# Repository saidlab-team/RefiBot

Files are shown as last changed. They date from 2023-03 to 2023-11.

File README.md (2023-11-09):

# RefiBot

<div align="center">
    <h1>🤖🛠️ RefiBot 🛠️🤖</h1>
</div>

<p align="center">
<a href="https://github.com/saidlab-team/RefiBot/blob/main/LICENSE" target="_blank">
    
</a>


<a href="https://twitter.com/socialdroneslab" target="_blank">
    
</a>

> A small educational robot made from recycled plastic from fishnets

RefiBot is an open-source educational robot designed to be built at home using recycled plastics from fishnets, promoting sustainability and encouraging learning.
The project includes hardware designs, software libraries, and documentation to help you build and program your RefiBot.

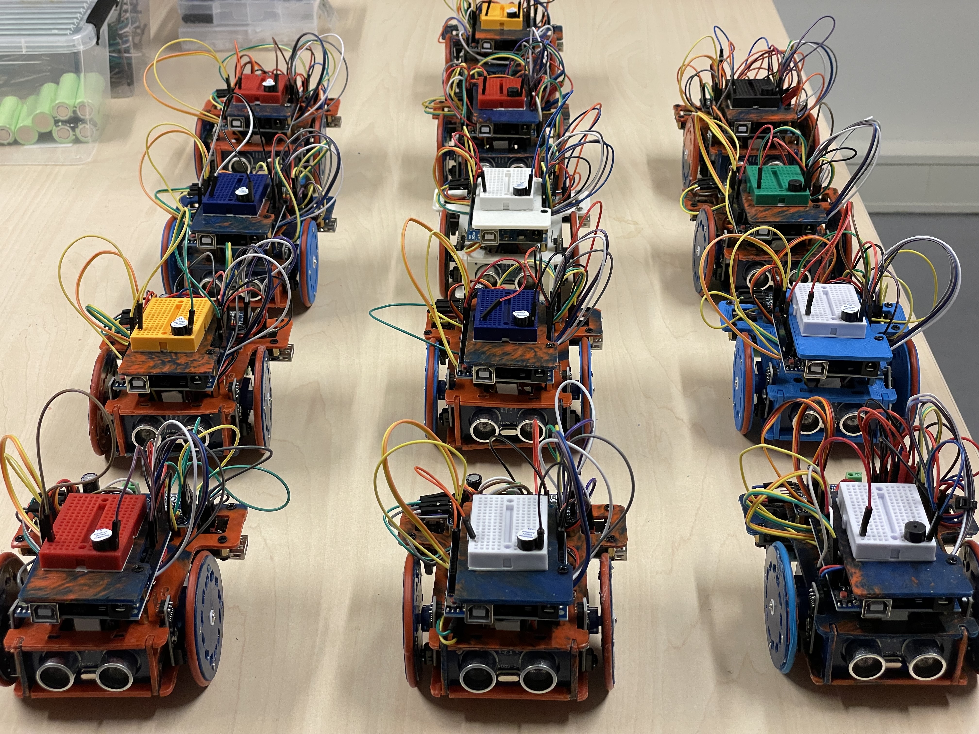
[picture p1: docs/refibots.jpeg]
RefiBot_Image


Citing
-------

Please cite the  following paper ([https://www.sciencedirect.com/science/article/pii/S2468067223000913](https://www.sciencedirect.com/science/article/pii/S2468067223000913)) when using ReFiBot for your research:

```bibtex
  @article{PANTOS2023Refibot,
    title = {The ReFiBot makers guide: Fostering academic open science and circularity with a robotic educational kit},
    journal = {HardwareX},
    volume = {16},
    pages = {e00484},
    year = {2023},
    issn = {2468-0672},
    doi = {https://doi.org/10.1016/j.ohx.2023.e00484},
    url = {https://www.sciencedirect.com/science/article/pii/S2468067223000913},
    author = {Christos Pantos and Jurrian Doornbos and Gonzalo Mier and João Valente},
    keywords = {Robotics, Education, Circularity, Open-science, Recycling, Low-cost}
  }
```

# Table of Contents

- [Features](#features)
  - [Key Features](#key-features)
  - [Possible Applications](#possible-applications)
- [Hardware](#hardware)
  - [Main Components](#main-components)
  - [Laser-cut parts](#laser-cut-parts)
- [Software](#software)
  - [What's supported](#whats-supported)
  - [Dependencies](#dependencies)
  - [Example](#example)
- [Demo Video](#demo-video)
- [Contributing](#contributing)
- [License](#license)

# Features

### Key Features

- Modular and customizable structure: RefiBot's laser-cut components are designed to fit together easily, making assembly and customization a breeze.
- Support for various sensors and actuators: RefiBot can be equipped with a wide range of sensors and actuators, such as distance sensors, light sensors, and servo motors, to adapt to different tasks.
- Pre-programmed example code: The provided `example.ino` Arduino sketch is the perfect start point to explore the functions of RefiBot. We also recommend you to take a look at the [Tutorial](docs/README.md)
- Open-source software and hardware: RefiBot's design files, software libraries, and example code are all open-source, encouraging collaboration and modification to suit your needs.

### Possible Applications

RefiBot's flexibility makes it an ideal platform for a variety of applications, including:

- Robotics education: Teach programming and robotics concepts using RefiBot as a hands-on learning tool.
- Research and development: Use RefiBot as a test platform for new algorithms, sensors, or actuators.
- Artistic installations: RefiBot's unique appearance and movement capabilities can be used in interactive installations or performances.

The possibilities for RefiBot are only limited by your imagination and creativity. We encourage you to explore its potential and share your own customizations and applications with the community.

# Hardware

The RefiBot is a robotic platform built using various hardware components, including motors, sensors, and controllers.

### Main Components

- Arduino Uno
- Servo motors
- TCS34725 color sensor
- PCA9685 PWM servo driver
- QTR reflectance sensor array for line following
- HC-SR04 ultrasonic sensor
- Buzzer for audio feedback
- Power supply (LiPo battery, or USB)
- Several laser-cut parts

### Laser-cut parts

The robot consists of the following parts, whose design files are available in the `hardware` folder:

1. Ball Holder (`Ball_Holder.png`)
2. Bottom Plate (`Bottom_Plate.png`)
3. Front Plate (`Front_Plate.png`)
4. IR Focus - Dark (`IR_Focus_Dark.png`)
5. IR Focus - Light (`IR_Focus_Light.png`)
6. Left Wheel Disk (`Left_Wheel_Disk.png`)
7. M3 Spacer (`M3_Spacer.png`)
8. Protective Plate (`Protective_Plate.png`)
9. Right Wheel Disk (`Right_Wheel_Disk.png`)
10. Robot Stand (`Robot_Stand.png`)
11. Side Plate (`Side_Plate.png`)
12. Top Plate (`Top_Plate.png`)

# Software

The library `software/awesome_lib.h` provides a set of functions and definitions for controlling the sensors of the RefiBot.

### What's supported

- TCS34725 color sensor support
- PCA9685 PWM servo driver support
- QTR reflectance sensor array support for line following
- HC-SR04 ultrasonic sensor support
- Buzzer support for audio feedback
- Wheel odometry with proximity sensors
- Motor control functions for movement (forward, backward, left, right)
- Sonar distance measurement
- Color reading with RGB values

### Dependencies

- Arduino.h
- Wire.h
- Adafruit_TCS34725.h
- Adafruit_PWMServoDriver.h
- QTRSensors.h
- Adafruit_NeoPixel.h

### Example

Please refer to the `example.ino` file in the `software` folder for a sample usage of the library in an Arduino sketch.

The example provided initializes the sensors using the `default_config_setup()` function and prints "Hello World" on the serial monitor:

```cpp
#include "awesome_lib.h"  //Include the awesome library

void setup(){
  default_config_setup();  // Initialize all the sensors
}

void loop(){
  Serial.println("Hello World");  // Print "Hello World" on the serial monitor
}
```

To learn more about how to use this robot, please, [check the Tutorial](docs/README.md)

# Demo Video

Watch the demo video!

## Contributing

Any contribution is welcome!
Apart from pull requests you can [open an issue](https://github.com/saidlab-team/RefiBot/issues/new/choose) to report bugs.
For feature requests, general ideas, or any broader topic, please use the [Discussions section](https://github.com/saidlab-team/RefiBot/discussions).

# License

This project (hardware and software) is licensed under the GPL3 license - see the [LICENSE](LICENSE) file for details.

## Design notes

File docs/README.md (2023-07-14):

# ReFiBot Overiew and Examples
ReFiBot stands for Recycled Fishnet Robot, as the frame of the robot is made from recycled fishnets. This document goes through some of the features of the robot, and how to program it to perform certain functions. We recommend going through the examples below as a starting point, but please explore all the functions we have madwe available, or even better: program your own and join the ReFiBot community!

## Overview

### Safety Measures

**Do not remove the battery!**

ReFiBot runs on Li-Ion batteries, these batteries have a lot of power in a small package and have enabled a lot of great technologies, such as electric cars.  However, they must be handled with care, otherwise, they can be quite dangerous. Have in mind that these are not like the typical AA Alkaline batteries, but high-powered 18650 Li-Ion batteries and this is why we you should take extra care in handling and ensuring the + and - are located correctly.

### Turning on the robot

In order to start the robot please turn on the power switch which is located on the rear-left side of the robot. Then, a red LED will flash meaning that the battery provides the necessary power to electronics.

You will notice that the robot can also turn on when it is connected to a PC via a USB cable. The USB connection can provide a limited amount of power, therefore it is strongly recommended to turn on the power switch first before you connect the robot to a PC.

### Upload software on the robot

In order to give life to the robot,  instructions in the form of a program should be uploaded to its memory. In order to do that:

1. Execute the Arduino IDE.
2. Connect the ReFiBot to your PC using the provided USB cable.
3. Copy the programs we have prepared for you into the Arduino IDE code editor.
4. Verify that the right port is selected.
5. Click the upload button.

### Available functions

| Sensors | Functions | Explanation |
|---|---|---|
| Time management | `void wait(float n secs)` | Wait `n` seconds |
| | `void wait_for_serial_input()` | Wait until the serial monitor receives something |
| QTR-8 IR line tracker | `uint16_t read_line_black_position()` | Return the position of the black line under the RefiBot |
| | `bool* black_line_array()` | Read the sensor values |
| | `int array_count(bool* arr)` | Return the number of sensors that see black under the robot |
| TCS34725 RGB sensor  | `float* read_rgb_sensor()` | Return three values with the color of the point in front of the camera, coded as `[R,G,B]` |
| HC-SR04 Ultrasonic sensor  | `float get_sonar_distance()` | Return the distance (cm) from the sensor to the object in front of it |
| Buzzer | `void buzzer_sound(float time)` | Make a 100Hz sound for `time` seconds |
| | `void buzzer_number(int n beeps)`  | Beep `n` times |
| Motors | `void stop_robot()` | Stop both motors |
| | `void go_front()` | Move both motors at the same speed |
| | `void go_back()` | Move both motors backward at the same speed |
| | `void go_right()` | Move the left motor forward faster than the right motor |
| | `void go_left()` | Move the right motor forward faster than the left motor |

## Some examples
### Wheel calibration and setup

The automatic adjustment might not work too well, such as left and right not moving at the same speed, or stop_robot not stopping the robot. If this is the case, you need to change the wheel_stable points to values between 330 and 350. Do this until they stop when only running stop_robot(). Copy-paste the code below to your sketch, and add the direction and setMotorsStablePoints(x,x)  in your setup() for the rest of the tutorial.

```cpp
#include "awesome_lib.h"

void setup() {
  left_wheel_front_dir = 1;  // If left wheel goes the wrong direction, change the value 1 to -1
  right_wheel_front_dir = 1; // If right wheel goes the wrong direction, change the value 1 to -1

  // First parameter is for left wheel (range between 330-350)
  // Second parameter is for right wheel (range between 330-350)
  setMotorsStablePoints(340, 340);

  default_config_setup();  // Initialize all the sensors (Do not alter this line)!
}
void loop() {
  stop_robot();  // Stop Robot (Check if both wheels stop)
  wait(1.0);     // Wait for 1 second
}
```

### The ultrasonic sensor

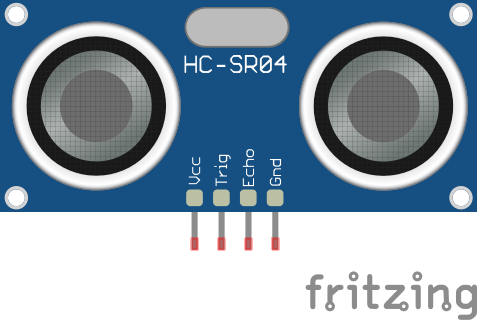
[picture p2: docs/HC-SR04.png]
HC-SR04 ultrasonic sensor


HC-SR04 ultrasonic sensor

This sensor measures the time it takes the sound to bounce off of objects. The sensor sends an ultrasonic pulse burst (outside of our hearing spectrum) which travels through the air, hits an object, and then bounces back to the sensor. This is also how bats and dolphins use echolocation. Then, the distance is calculated using the following formula:

$$
Distance = SoundSpeed * Time/2
$$

Fortunately, the provided code calculates automatically the distance for you.

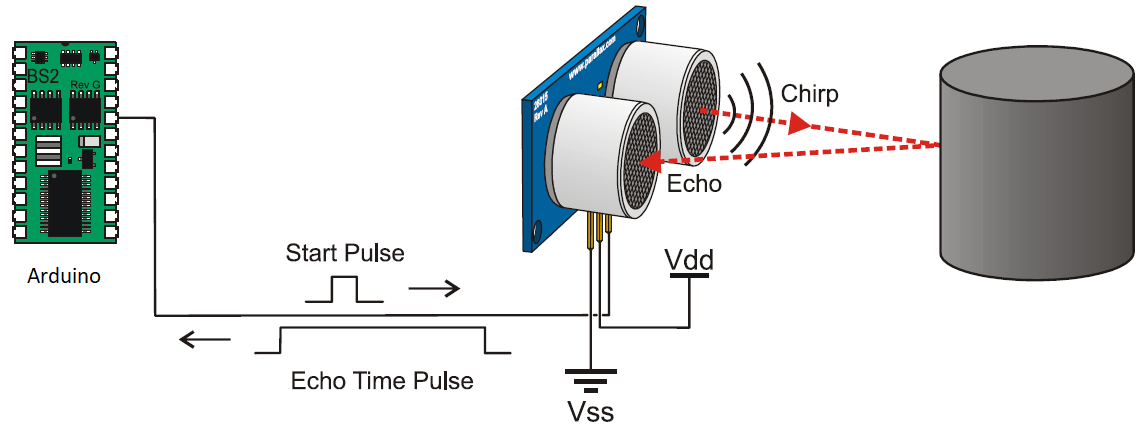
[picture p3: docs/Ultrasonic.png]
Working principle of the ultrasonic sensor


Working principle of the ultrasonic sensor

An easy interface to the sonar is the ***get_sonar_distance()*** function, in which all of the above is already executed.

```cpp
#include "awesome_lib.h"

void setup() {
  default_config_setup();  // Initialize all the sensors (Do not alter this line)!
}

void loop(){
  float distance = get_sonar_distance();  // Read distance (cm)
  Serial.print("Measured distance: ");    // Print results
  Serial.print(distance);
  Serial.println(" cm");
  wait(0.2);                              // Wait for 0.2 seconds
}
```

### Ultrasonic Wall Detection and Counting

More complex behaviours can always be programmed by combining the different functions. For example we can count the number of walls it has detected. Starting with when a distance larger than 20cm is detected, the robot moves forward until the next sensor reading. But if the distance is equal or less than 20cm, it stops, beeps (for the number of walll counts), moves backward, and rotates right. After this, it loops back to the decision process to re-evaluate the distance.

```cpp
#include "awesome_lib.h"

static int WALL_COUNT = 0;

void setup() {
  left_wheel_front_dir = 1;  // If left wheel go backward, change the value 1 to -1
  right_wheel_front_dir = 1;  // If right wheel go backward, change the value 1 to -1

  // First parameter is for left wheel (range between 330-350)
  // Second parameter is for right wheel (range between 330-350)
  setMotorsStablePoints(340, 340);
  default_config_setup();  // Initialize all the sensors (Do not alter this line)!
}

void loop() {
  float dist = get_sonar_distance(); // Read the distance
  Serial.print("distance: ");        // Print the result
  Serial.print(dist);
  Serial.println(" cm");

  // check the distance, if it is lower than 20, execute the commands below
  if (dist < 20.0) {
    stop_robot();       // Stop the robot
    WALL_COUNT+=1;      // Increase wall count numvber
    buzzer_nummber(WALL_COUNT);  // Beep for total wall count
    wait(0.2);          // Wait for 0.3 seconds
    go_back();          // Go back
    wait(0.2);          // and wait 0.2 seconds
    go_right();         // turn right
    wait(0.2);          // wait 0.2 seconds
  } else{               // else move forwards
    go_front();         // go straight
    wait(0.2);          // wait 0.2 seconds
  }
}
```

The code above is the implementation of this flowchart in the Arduino language. Please note that the delay statements are there to make the robot has time to move a little. This is somewhat similar to how a vacuum robot behaves, without a mapping algorithm, however.

### RGB colour detection sensor

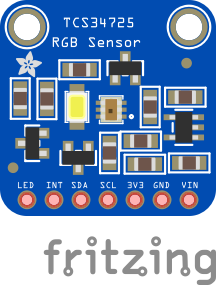
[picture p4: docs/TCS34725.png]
RGB colour sensor


The TCS34725 board works like a tiny, one-pixel camera that is capable to sense and quantify the colour values of the reflected light when an object is placed in front of it. As you can see on the bottom of the ReFiBot, this sensor is also equipped with a white LED to ensure sufficient light intensity for taking good measurements.

In order to use this sensor, you can use the ***read_rgb_sensor()*** function, which interfaces with the sensor and returns the intensity of the red, green and blue channels as a value between 0 and 255.

```cpp
#include "awesome_lib.h"

void setup() {
  default_config_setup(); // Initialize all the sensors (Do not alter this line)!
}

void loop() {
  float* colours = read_rgb_sensor();  // Read the sensor

  Serial.print("The sensed RGB: ");    // Print the results
  float R = colours[0];
  float G = colours[1];
  float B = colours[2];
  Serial.print("R: ");
  Serial.print(R);
  Serial.print(" ");
  Serial.print(" G: ");
  Serial.print(G);
  Serial.print(" ");
  Serial.print(" B: ");
  Serial.print(B);
  Serial.println(" ");
}
```

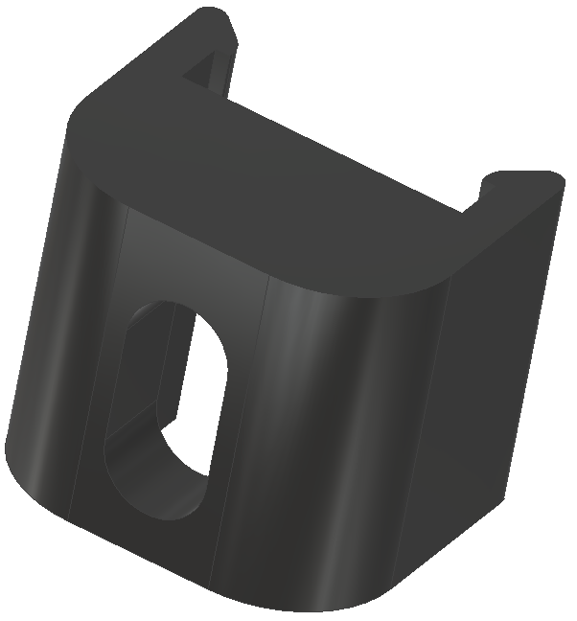
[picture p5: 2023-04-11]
hardware/IR_Focus_Dark.png

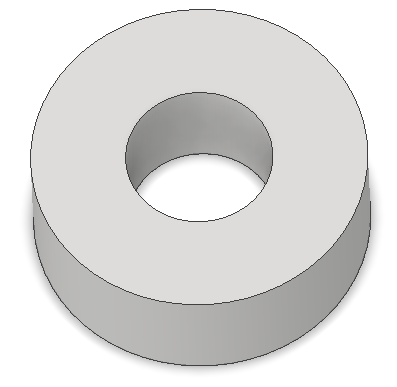
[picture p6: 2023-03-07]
hardware/M3_Spacer.png

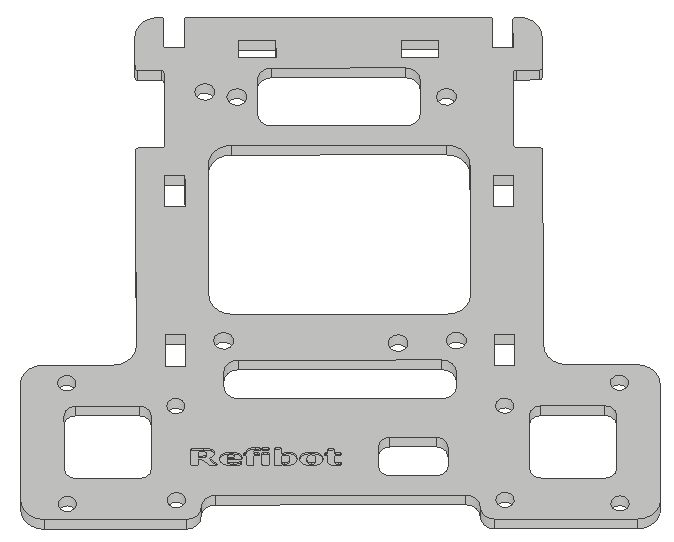
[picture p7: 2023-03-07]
hardware/Top_Plate.png

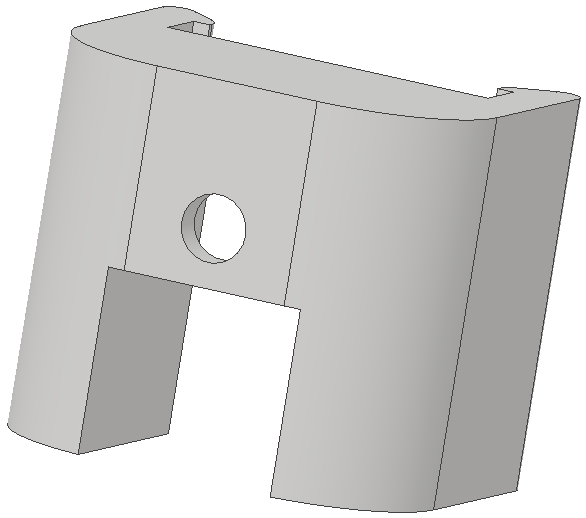
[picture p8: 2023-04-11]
hardware/IR_Focus_Light.png

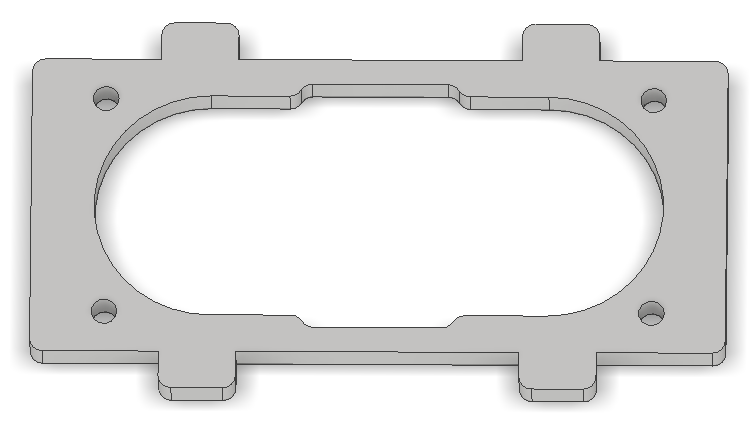
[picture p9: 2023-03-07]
hardware/Front_Plate.png

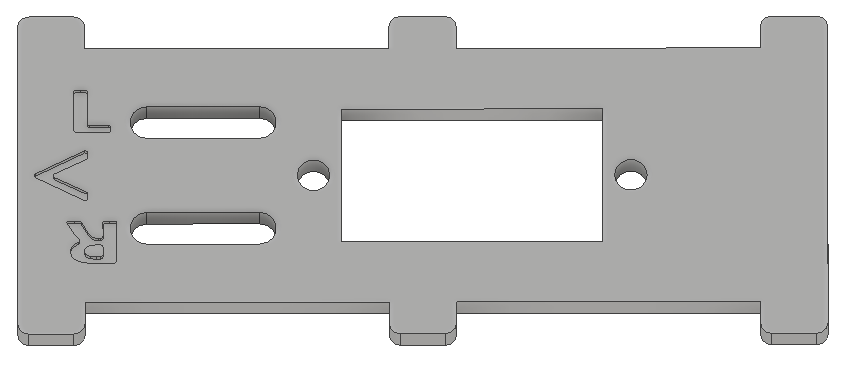
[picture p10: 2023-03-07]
hardware/Side_Plate.png

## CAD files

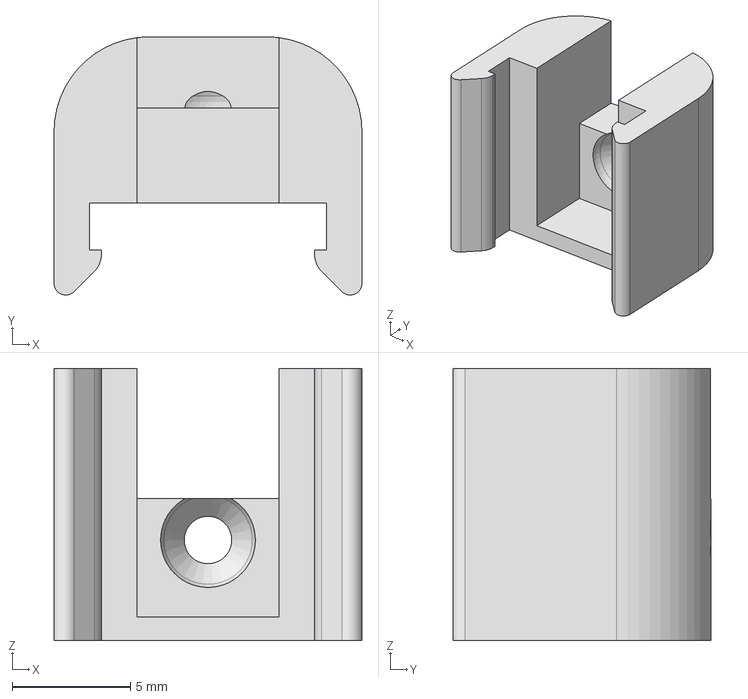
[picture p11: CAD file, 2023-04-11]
hardware/IR_Focus_Light.stp
13.0 x 10.9 x 11.5 mm

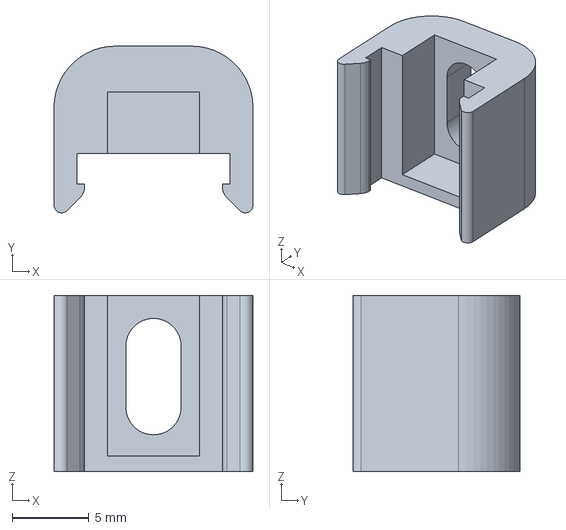
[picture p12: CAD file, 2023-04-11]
hardware/IR_Focus_Dark.stp
13.0 x 10.9 x 11.5 mm

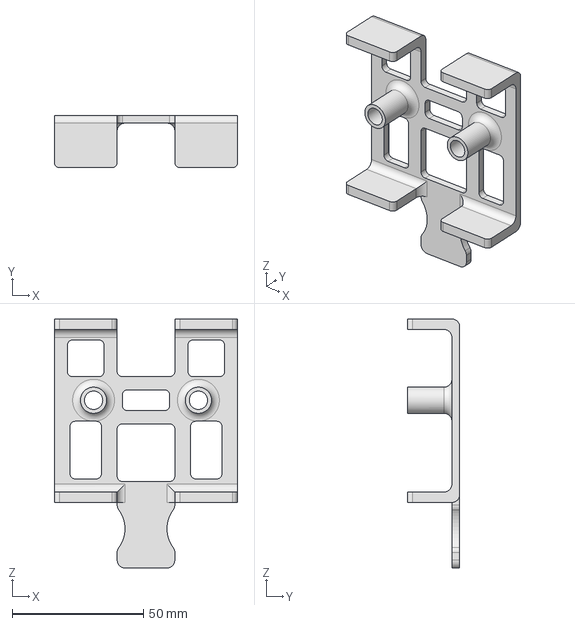
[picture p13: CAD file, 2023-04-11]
hardware/Robot_Stand.stp
70.0 x 20.0 x 95.0 mm

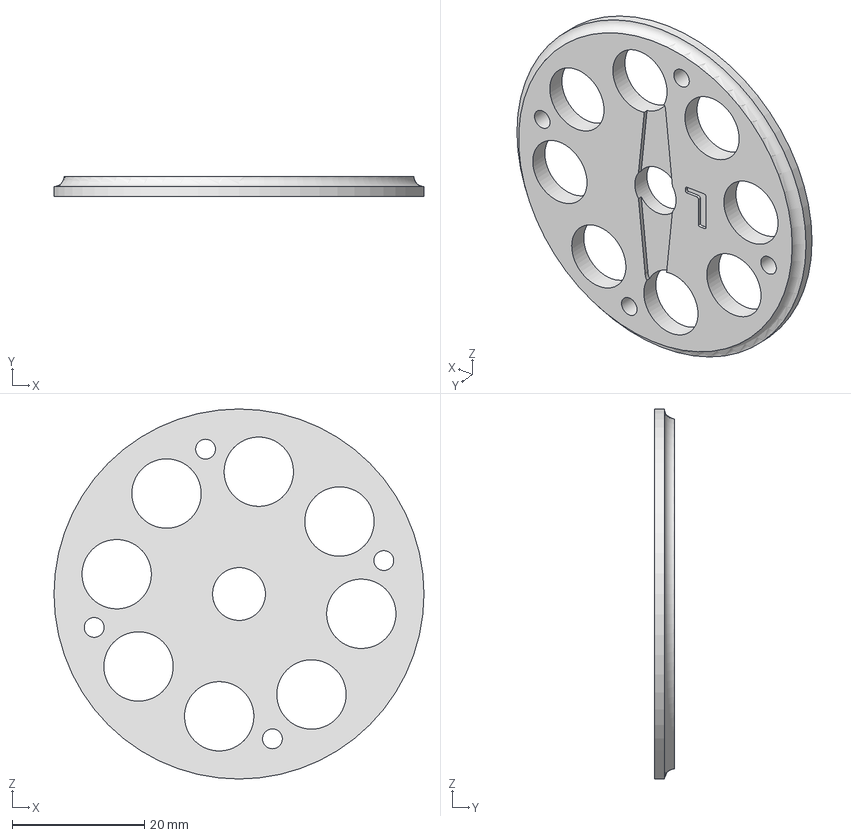
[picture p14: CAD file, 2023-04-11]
hardware/Wheel_L_Disk.stp
56.0 x 3.00 x 56.0 mm

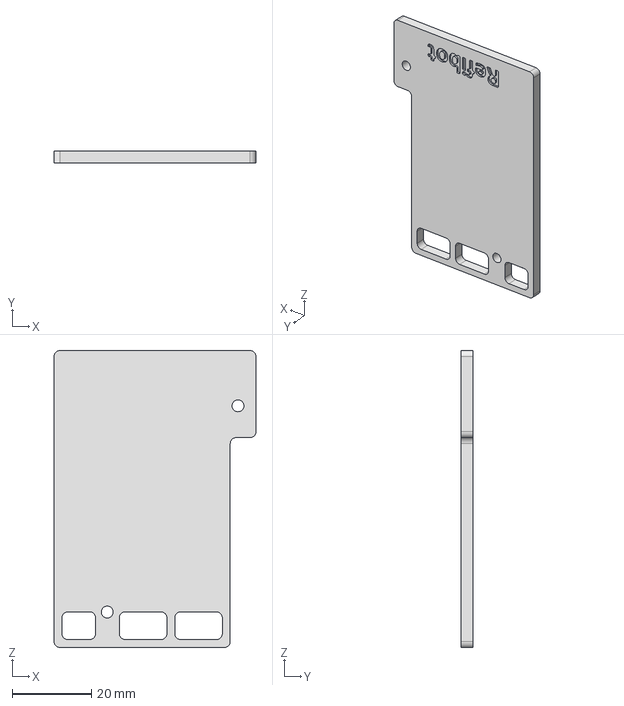
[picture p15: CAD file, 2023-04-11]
hardware/Protective_Plate.stp
51.0 x 3.00 x 75.0 mm

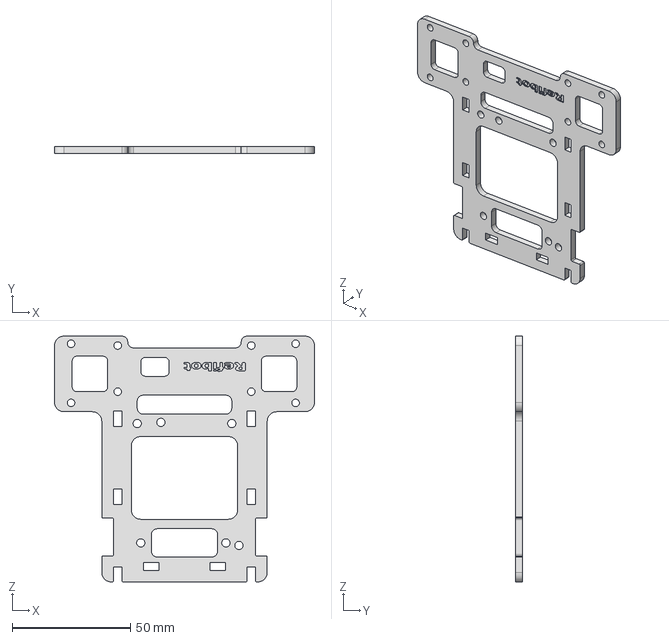
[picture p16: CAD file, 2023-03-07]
hardware/Top_Plate.stp
110.0 x 3.00 x 104.0 mm

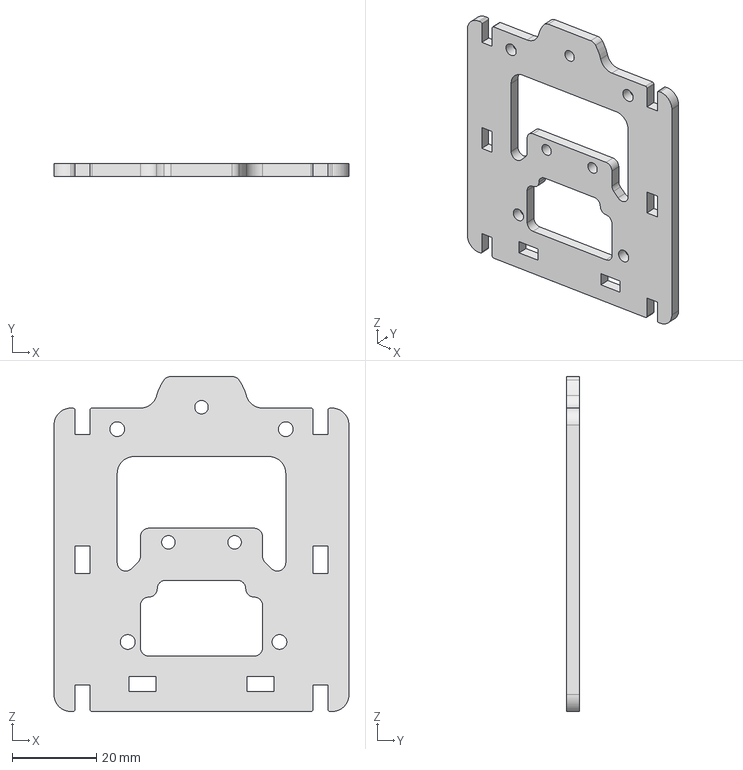
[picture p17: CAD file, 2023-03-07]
hardware/Bottom_Plate.stp
70.0 x 3.00 x 79.5 mm

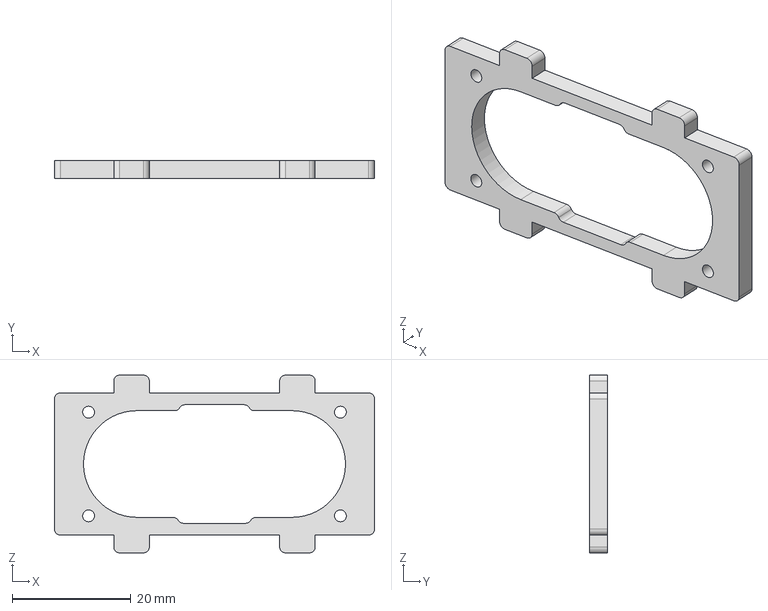
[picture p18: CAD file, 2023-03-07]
hardware/Front_Plate.stp
54.0 x 3.00 x 30.0 mm

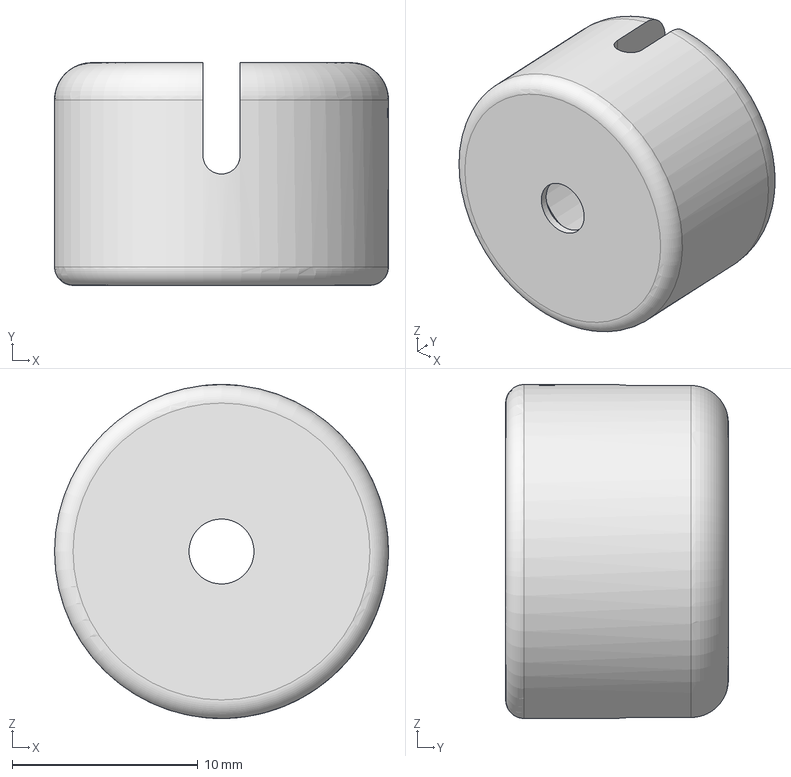
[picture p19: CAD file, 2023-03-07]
hardware/Ball_Holder.stp
18.0 x 12.0 x 18.0 mm

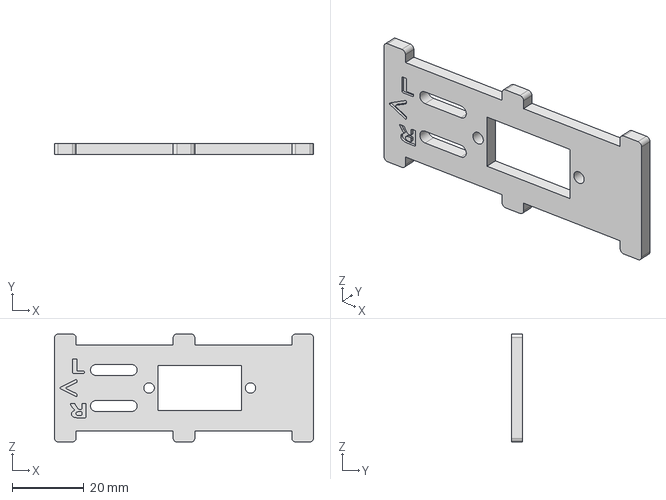
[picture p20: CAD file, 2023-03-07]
hardware/Side_Plate.stp
72.0 x 3.00 x 30.0 mm

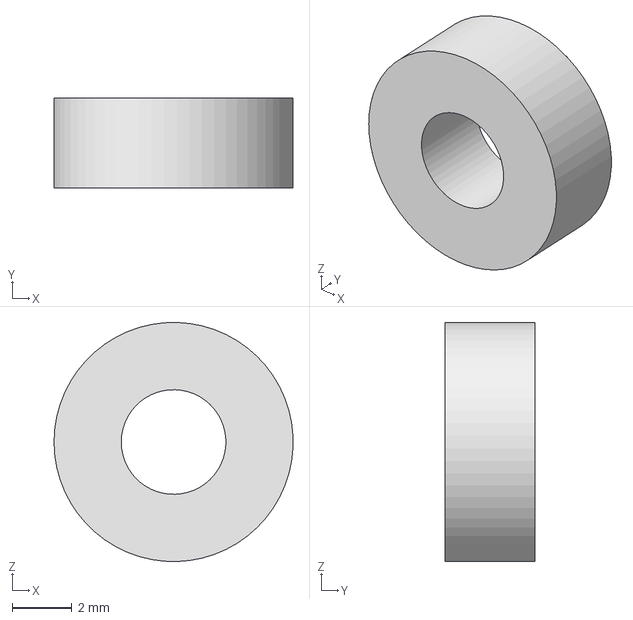
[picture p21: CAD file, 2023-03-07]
hardware/M3_Spacer.stp
7.99 x 3.00 x 8.00 mm

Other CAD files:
hardware/Wheel_R_Disk.stp
hardware/Ball_Holder.ipt
hardware/Ball_Holder.stl
hardware/Bottom_Plate.ipt
hardware/Bottom_Plate.stl
hardware/Front_Plate.ipt
hardware/Front_Plate.stl
hardware/IR_Focus_Dark.ipt
hardware/IR_Focus_Dark.stl
hardware/IR_Focus_Light.ipt
hardware/IR_Focus_Light.stl
hardware/M3_Spacer.ipt
hardware/M3_Spacer.stl
hardware/Protective_Plate.ipt
hardware/Protective_Plate.stl
hardware/Robot_Stand.ipt
hardware/Robot_Stand.stl
hardware/Side_Plate.ipt
hardware/Side_Plate.stl
hardware/Top_Plate.ipt
hardware/Top_Plate.stl
hardware/Wheel_L_Disk.ipt
hardware/Wheel_L_Disk.stl
hardware/Wheel_R_Disk.ipt
hardware/Wheel_R_Disk.stl

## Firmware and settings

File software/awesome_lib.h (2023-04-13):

//=============================================================================
//    Copyright (C) 2022-2023 Wageningen University - All Rights Reserved
//            Author: Gonzalo Mier & Jurrian Doornbos
//
//
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

#ifndef AWESOME_LIB_H
#define AWESOME_LIB_H

#include <Arduino.h>
#include <Wire.h>
#include <Adafruit_TCS34725.h>
#include <Adafruit_PWMServoDriver.h>
#include <QTRSensors.h>
#include <Adafruit_NeoPixel.h>


#define SERVOMIN  88  // This is the 'minimum' pulse length count (out of 4096) (org=150)
#define SERVOMAX  320 // This is the 'maximum' pulse length count (out of 4096) (org=600)
#define USMIN  600    // This is the rounded 'minimum' microsecond length based on the minimum pulse of 150 (org=600)
#define USMAX  2400   // This is the rounded 'maximum' microsecond length based on the maximum pulse of 600(org=2400)
#define SERVO_FREQ 60 // Analog servos run at ~50 Hz updates (org=50)

#define DEFAULT_WHEEL_STABLE 340 // Value of stable point if none found
#define WHEEL_FRONT 120
#define WHEEL_BACK -120
int left_wheel_front_dir {1}; // Dir of the wheel when going to front. Change to -1 if opposite dir
int right_wheel_front_dir {1}; // Dir of the wheel when going to front. Change to -1 if opposite dir
int left_wheel_stable_point {DEFAULT_WHEEL_STABLE};
int right_wheel_stable_point {DEFAULT_WHEEL_STABLE};
volatile int left_wheel_count = 0; // Count for the odometry
volatile int right_wheel_count = 0; // Count for the odometry
volatile int left_wheel_dir = 0; // Direction for the odometry
volatile int right_wheel_dir = 0; // Direction for the odometry


#define BLACK_LINE_THRESHOLD 700 // Value of black line treshold
#define NUM_FOLLOW_LINE             4  // number of sensors used
#define NUM_SAMPLES_PER_FOLLOW_LINE  4  // average 4 analog samples per sensor reading
#define EMITTER_PIN             4  // emitter is controlled by digital pin 4

#define PROX_SENSOR_LEFT 3    // Pin for the odometry sensor in the left wheel
#define PROX_SENSOR_RIGHT 2    // Pin for the odometry sensor in the right wheel

#define echoPin 6     // attach pin D6 Arduino to pin Echo of HC-SR04
#define trigPin 5     //attach pin D5 Arduino to pin Trig of HC-SR04

const int buzzer = 7; //buzzer to arduino pin 7




bool call_calibrate_follow_line_cameras {false};
bool call_calibrate_motors = {false};

bool proximity_sensor_left_connected {false};
bool proximity_sensor_right_connected {false};


Adafruit_TCS34725 tcs = Adafruit_TCS34725(TCS34725_INTEGRATIONTIME_50MS, TCS34725_GAIN_4X);
Adafruit_PWMServoDriver pwm = Adafruit_PWMServoDriver();

// defines variables
//long duration; // variable for the duration of sound wave travel
//int distance; // variable for the distance measurement
uint8_t L_servo = 0; // our servo # counter
uint8_t R_servo = 1; // our servo # counter

QTRSensors qtra;
unsigned int sensorValues[NUM_FOLLOW_LINE];

void count_prox_sensor_left(void) {
  left_wheel_count += left_wheel_dir;
}

void count_prox_sensor_right(void) {
  right_wheel_count += right_wheel_dir;
}

void setMotorsStablePoints(int left_wheel, int right_wheel) {
  left_wheel_stable_point = left_wheel;
  right_wheel_stable_point = right_wheel;
}



// time in seconds
void wait(float time) {
  delay(time * 1000);
}

void wait_for_serial_input() {
  while(Serial.available() == 0) {}
}



// time in seconds
void buzzer_sound(float time) {
  tone(buzzer, 100); // Send 100Hz sound signal...
  wait(time);        // ...for some time
  noTone(buzzer);     // Stop sound...
}

void buzzer_number(int no_beeps) {
  for (int i = 0; i < no_beeps; i++) {
    buzzer_sound(0.1);
    wait(0.1);
  }
}




float* read_rgb_sensor() {
  float red, green, blue;

  tcs.setInterrupt(false);  // turn on LED

  delay(60);  // takes 50ms to read

  tcs.getRGB(&red, &green, &blue);

  tcs.setInterrupt(true);  // turn off LED
  static float color[3];
  color[0] = red;
  color[1] = green;
  color[2] = blue;
  return color;
}


float get_sonar_distance() {
  // defines variables
  long duration; // variable for the duration of sound wave travel
  int distance; // variable for the distance measurement

  // Clears the trigPin condition
  digitalWrite(trigPin, LOW);
  delayMicroseconds(2);

  // Sets the trigPin HIGH (ACTIVE) for 10 microseconds
  digitalWrite(trigPin, HIGH);
  delayMicroseconds(10);
  digitalWrite(trigPin, LOW);

  // Reads the echoPin, returns the sound wave travel time in microseconds
  duration = pulseIn(echoPin, HIGH);

  // Calculating the distance
  return duration * 0.034 / 2;       // Speed of sound wave divided by 2 (go and back)
}

void stop_robot(void) {
  pwm.setPWM(L_servo, 0, left_wheel_stable_point);
  pwm.setPWM(R_servo, 0, right_wheel_stable_point);
}

void go_front(void) {
  pwm.setPWM(L_servo, 0, left_wheel_stable_point + left_wheel_front_dir * WHEEL_FRONT);
  pwm.setPWM(R_servo, 0, right_wheel_stable_point + right_wheel_front_dir * WHEEL_FRONT);
  left_wheel_dir = 1;
  right_wheel_dir = 1;
}

void go_back(void) {
  pwm.setPWM(L_servo, 0, left_wheel_stable_point + left_wheel_front_dir * WHEEL_BACK);
  pwm.setPWM(R_servo, 0, right_wheel_stable_point + right_wheel_front_dir * WHEEL_BACK);
  left_wheel_dir = -1;
  right_wheel_dir = -1;
}

void go_right(void) {
  pwm.setPWM(L_servo, 0, left_wheel_stable_point + left_wheel_front_dir * WHEEL_FRONT);
  pwm.setPWM(R_servo, 0, right_wheel_stable_point + right_wheel_front_dir * WHEEL_BACK);
  left_wheel_dir = 1;
  right_wheel_dir = -1;
}

void go_left(void) {
  pwm.setPWM(L_servo, 0, left_wheel_stable_point + left_wheel_front_dir * WHEEL_BACK);
  pwm.setPWM(R_servo, 0, right_wheel_stable_point + right_wheel_front_dir * WHEEL_FRONT);
  left_wheel_dir = -1;
  right_wheel_dir = 1;
}


uint16_t read_line_black_position(void) {
  return qtra.readLineBlack(sensorValues);
}

//some function to give array of true false values and black line position
bool* black_line_array(void) {
  static bool line_array[NUM_FOLLOW_LINE];

  for (int i = 0; i < NUM_FOLLOW_LINE; i++) {
    line_array[i] = sensorValues[i] > BLACK_LINE_THRESHOLD;
  }
  return line_array;
}

void print_black_line_array_to_string(bool* arr) {
  for (int i = 0; i < NUM_FOLLOW_LINE; ++i) {
    Serial.print(arr[i]);
    Serial.print(" ");
  }
}

// Only for follo line follower
int array_count(bool* arr) {
  int sum = 0;
  for (int i = 0; i < NUM_FOLLOW_LINE; i++) {
    sum = sum + arr[i];
  }
  return sum;
}


void follow_line(int error) {
  int Kp = 3;

  int adjust = Kp * error;

  float L_speed =  left_wheel_front_dir * (WHEEL_FRONT - adjust);
  float R_speed =  right_wheel_front_dir * (WHEEL_FRONT - adjust);

  pwm.setPWM(L_servo, 0, left_wheel_stable_point + L_speed);
  pwm.setPWM(R_servo, 0, right_wheel_stable_point + R_speed);
  delay(50);
}


int read_prox_sensor_left(void) {
  return digitalRead(PROX_SENSOR_LEFT);
}

int read_prox_sensor_right(void) {
  return digitalRead(PROX_SENSOR_RIGHT);
}
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

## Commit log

2023-04-11 Add .ipt files and renaming
    [Arduino_Protector.stp, Ball_Holder.ipt, Bottom_Plate.ipt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]
2023-04-11 Add robot stand part
    [Robot_Stand.ipt, Robot_Stand.stl, Robot_Stand.stp]
2023-04-11 Add IR focus parts for lighter and darker filaments
    [IR_Focus_Dark.ipt, IR_Focus_Dark.stl, IR_Focus_Dark.stp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]
2023-04-13 Rename wheel disk parts
    [Wheel_L_Disk.ipt, Wheel_L_Disk.stl, Wheel_L_Disk.stp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]

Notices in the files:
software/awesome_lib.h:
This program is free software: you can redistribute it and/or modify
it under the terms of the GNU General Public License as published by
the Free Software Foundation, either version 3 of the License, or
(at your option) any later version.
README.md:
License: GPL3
